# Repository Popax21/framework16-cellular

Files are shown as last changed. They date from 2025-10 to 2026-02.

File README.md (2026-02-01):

# Framework Laptop 16 M.2 Cellular Modem Expansion Bay Module

> [!IMPORTANT]
> ### This design is still a work-in-progress, and should currently be considered non-functional!
>
> The current revision contained in this repository (v1.1) still has some glaring design defects, and as such will need at least one more revision to fully bug-fix.
> As of now I am focusing on other projects, so there is no timeline for when development of the module will resume.

This repository holds the WIP design files for a module for the Framework Laptop 16's Expansion Bay allowing for the connection of a standard M.2 B-Key cellular modem, also featuring a microSIM connector for the insertion of a standard SIM card.
It was designed for usage with Quectel RM50X / RM5X0-series 5G modules, but other 3.7V-tolerant modules are expected to work as well.

> [!WARNING]
> This module provides the M.2 slot with a VCC of 3.7V, and not the standard 3.3V!
> This is the recommended voltage of the Quectel modems the module is designed around, but you may have to adapt the schematic in case you want to use a different module.

The module provides the M.2 slot with both a PCI-E x1 interface as well as an USB2 HS (max 480Mbps) interface, however routing priority has been given to the PCI-E lane, so the full bandwith may not be available over the USB port.
Note that no USB3.x interface has been routed to the slot!
This means that in practice you should be able to use any M.2 cellular module, however only PCI-E capable modules will be able to provide high-speed connectivity.

> [!NOTE]
> This design decision is rooted in the Expanion Bay's interface to the rest of the computer, which only provides a single USB2 port for modules to use.
> Providing a full USB 3.0 (or higher) interface for the modem would have required the addition of a PCI-E USB host controller, which would have in turn complicated the PCI-E logic since now two separate REFCLK signals would be required.
> While there is support for receiving two separate REFCLKs from the mainboard since hardware revision 7, no such support was implemented to reduce the design complexity of the module.

Some functionality exposed by the board (i.e. hardware rfkill/airplane mode, modem resets / power-on shutdowns) are exposed behind an I2C GPIO port, and will require support from the Framework Laptop 16's EC (Embedded Controller) MCU to fully operate.
No such support has been developed as of now, however such support is planned to be released at a future date in the form of firmware patches.

All Expansion Bay modules feature an EEPROM which holds a "descriptor" for the installed module, which contains, among other things, the module's serial number as well as GPIO configuration.
By default the module should be picked as a Dual M.2 Expansion module until an appropriate descriptor has been written onto the EEPROM.
The PCB has been designed to still operate when treated as such an expansion module, however a proper custom EEPROM descriptor will be developed at a future date as part of EC integration.

No pre-packaged schematics / Gerber files are available at the moment, but a GH Actions pipeline may be set up at a future date.

> [!IMPORTANT]
> If you still plan on ordering a PCB through e.g. JLCPCB, ensure that you enable Impedance Matching and specifically select stackup JLC041611H-3313 as part of the checkout process.
> This stackup is required for the sensitive PCI-E / USB / RF signals to be properly impedance matched and not be distorted.

This design uses modified versions of the template PCB and FX Beam connector symbol / footprint published by jyancat, found [here](https://github.com/jyancat/ExpansionBay/tree/main/Electrical/KiCad_templates/Expansion_Bay).

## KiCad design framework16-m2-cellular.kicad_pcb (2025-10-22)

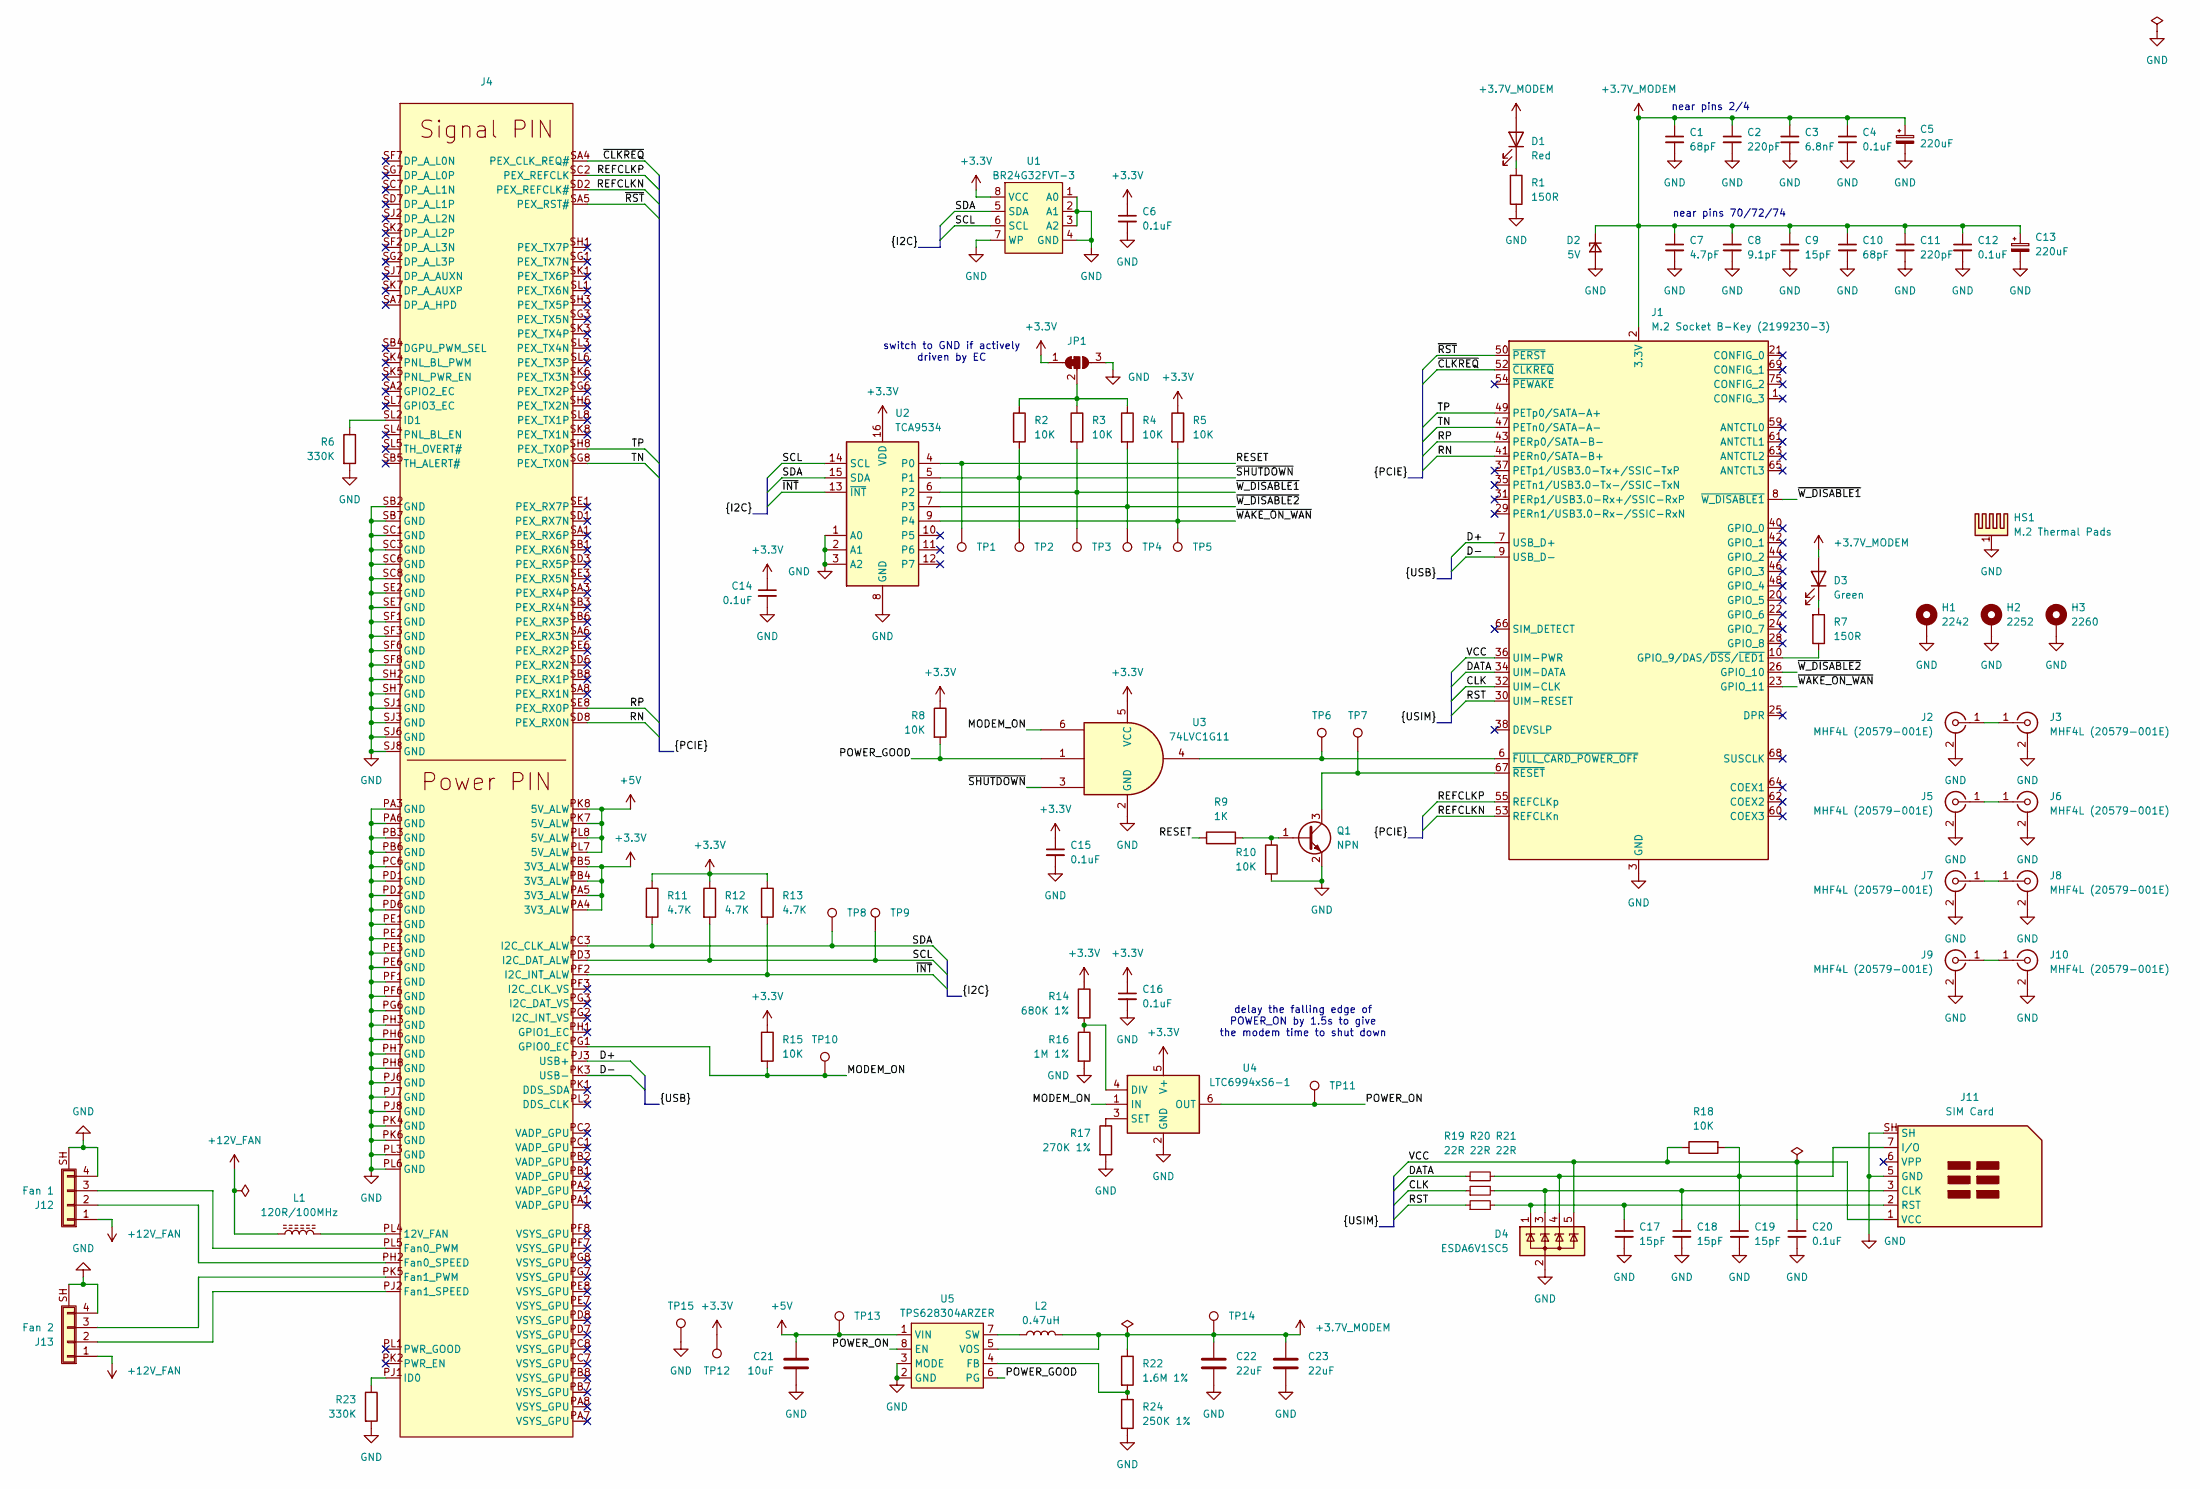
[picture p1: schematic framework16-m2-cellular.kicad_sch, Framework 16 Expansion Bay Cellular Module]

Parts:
C1, C10: 68pF; C_0603_1608Metric; LCSC C62782
C2, C11: 220pF; C_0603_1608Metric; LCSC C106210
C3: 6.8nF; C_0603_1608Metric; LCSC C162241
C4, C6, C12, C14, C15, C16, C20: 0.1uF; C_0603_1608Metric; LCSC C14663
C5, C13: 220uF; CP_Elec_6.3x5.4; LCSC C72494
C7: 4.7pF; C_0603_1608Metric; LCSC C1669
C8: 9.1pF; C_0603_1608Metric; LCSC C61817
C9, C17, C18, C19: 15pF; C_0603_1608Metric; LCSC C1644
C21: 10uF; C_0603_1608Metric; LCSC C19702
C22, C23: 22uF; C_1206_3216Metric; LCSC C90146
D1: Red; LED_0805_2012Metric; LCSC C94741
D2: 5V; D_SOD-523; LCSC C20932
D3: Green; LED_0805_2012Metric; LCSC C2297
D4: ESDA6V1SC5; SOT-23-5; LCSC C2935146
H1: 2242; MountingHole_2.2mm_M2_Pad
H2: 2252; MountingHole_2.2mm_M2_Pad
H3: 2260; MountingHole_2.2mm_M2_Pad
HS1: M.2 Thermal Pads; Thermal Pad
J1: M.2 Socket B-Key (2199230-3); CONN67_2199230_TEC; LCSC C590859
J2, J5, J7, J9: MHF4L (20579-001E); CONN_20579-001E_IPX; LCSC C434808
J3, J6, J8, J10: MHF4L (20579-001E); CONN_20579-001E_IPX; LCSC C5881005
J4: Expansion Bay FXBeam
J11: SIM Card; microSIM_JAE_SF53S006VCBR2000; LCSC C2929301
J12: Fan 1; AFC30-S04FCC-00; LCSC C395232
J13: Fan 2; AFC30-S04FCC-00; LCSC C395232
JP1: SolderJumper_3_Bridged12; SolderJumper-3_P1.3mm_Bridged12_RoundedPad1.0x1.5mm
L1: 120R/100MHz; R_0603_1608Metric; LCSC C14709
L2: 0.47uH; L_1008_2520Metric; LCSC C519277
Q1: NPN; SOT-23; LCSC C916392
R1, R7: 150R; R_0603_1608Metric; LCSC C22808
R2, R3, R4, R5, R8, R10, R15, R18: 10K; R_0603_1608Metric; LCSC C25804
R6, R23: 330K; R_0603_1608Metric; LCSC C23137
R9: 1K; R_0603_1608Metric; LCSC C21190
R11, R12, R13: 4.7K; R_0603_1608Metric; LCSC C23162
R14: 680K 1%; R_0603_1608Metric; LCSC C25822
R16: 1M 1%; R_0603_1608Metric; LCSC C22935
R17: 270K 1%; R_0603_1608Metric; LCSC C22965
R19, R20, R21: 22R; R_0603_1608Metric; LCSC C23345
R22: 1.6M 1%; R_0805_2012Metric; LCSC C5121530
R24: 250K 1%; R_0805_2012Metric; LCSC C5156563
TP1, TP2, TP3, TP4, TP5, TP6, TP7, TP8, TP9, TP10, TP11, TP12, TP13, TP14, TP15: TestPoint; TestPoint_Pad_D1.0mm
U1: BR24G32FVT-3; TSSOP-8_4.4x3mm_P0.65mm; LCSC C2061284
U2: TCA9534; TSSOP-16_4.4x5mm_P0.65mm; LCSC C783615
U3: 74LVC1G11; SOT-23-6; LCSC C22356918
U4: LTC6994xS6-1; TSOT-23-6; LCSC C581054
U5: TPS628304ARZER; WQFN-HR8_RZE_TEX; LCSC C33092582

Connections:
+3.3V: C6.1, C14.1, C15.1, C16.1, J4.PA4 (3V3_ALW), J4.PA5 (3V3_ALW), J4.PB4 (3V3_ALW), J4.PB5 (3V3_ALW), JP1.1 (A), R5.1, R8.1, R11.1, R12.1, R13.1, R14.1, R15.1, TP12.1, U1.8 (VCC), U2.16 (VDD), U3.5 (VCC), U4.5 (V+)
+3.7V_MODEM: C1.1, C2.1, C3.1, C4.1, C5.1, C7.1, C8.1, C9.1, C10.1, C11.1, C12.1, C13.1, C22.1, C23.1, D1.2 (A), D2.1 (K), D3.2 (A), J1.2 (3.3V), J1.4 (3.3V), J1.70 (3.3V), J1.72 (3.3V), J1.74 (3.3V), L2.2, R22.1, TP14.1, U5.5 (VOS)
+5V: C21.1, J4.PK7 (5V_ALW), J4.PK8 (5V_ALW), J4.PL7 (5V_ALW), J4.PL8 (5V_ALW), TP13.1, U5.1 (VIN)
+12V_FAN: J12.1, J13.1, L1.1
/CLK: J1.32 (UIM-CLK), R20.1
/D+: J1.7 (USB_D+), J4.PJ3 (USB+)
/D-: J1.9 (USB_D-), J4.PK3 (USB-)
/DATA: J1.34 (UIM-DATA), R19.1
/MODEM_ON: J4.PG1 (GPIO0_EC), R15.2, TP10.1, U3.6, U4.1 (IN)
/POWER_GOOD: R8.2, U3.1, U5.6 (PG)
/POWER_ON: TP11.1, U4.6 (OUT), U5.8 (EN)
/REFCLKN: J1.53 (REFCLKn), J4.SD2 (PEX_REFCLK#)
/REFCLKP: J1.55 (REFCLKp), J4.SC2 (PEX_REFCLK)
/RESET: R9.1, TP1.1, U2.4 (P0)
/RN: J1.41 (PERn0/SATA-B+), J4.SD8 (PEX_RX0N)
/RP: J1.43 (PERp0/SATA-B-), J4.SE8 (PEX_RX0P)
/RST: J1.30 (UIM-RESET), R21.1
/SCL: J4.PD3 (I2C_DAT_ALW), R12.2, TP9.1, U1.6 (SCL), U2.14 (SCL)
/SDA: J4.PC3 (I2C_CLK_ALW), R11.2, TP8.1, U1.5 (SDA), U2.15 (SDA)
/TN: J1.47 (PETn0/SATA-A-), J4.SG8 (PEX_TX0N)
/TP: J1.49 (PETp0/SATA-A+), J4.SH8 (PEX_TX0P)
/VCC: C20.1, D4.5 (K), J1.36 (UIM-PWR), J11.1 (VCC), R18.1
/~CLKREQ: J1.52 (~CLKREQ), J4.SA4 (PEX_CLK_REQ#)
/~INT: J4.PF2 (I2C_INT_ALW), R13.2, U2.13 (~INT)
/~RST: J1.50 (~PERST), J4.SA5 (PEX_RST#)
/~SHUTDOWN: R2.2, TP2.1, U2.5 (P1), U3.3
/~WAKE_ON_WAN: J1.23 (GPIO_11), R5.2, TP5.1, U2.9 (P4)
/~W_DISABLE1: J1.8 (~W_DISABLE1), R3.2, TP3.1, U2.6 (P2)
/~W_DISABLE2: J1.26 (GPIO_10), R4.2, TP4.1, U2.7 (P3)
GND: C1.2, C2.2, C3.2, C4.2, C5.2, C6.2, C7.2, C8.2, C9.2, C10.2, C11.2, C12.2, C13.2, C14.2, C15.2, C16.2, C17.2, C18.2, C19.2, C20.2, C21.2, C22.2, C23.2, D2.2 (A), D4.2 (A), H1.1, H2.1, H3.1, HS1.1, J1.3 (GND), J1.5 (GND), J1.11 (GND), J1.27 (GND), J1.33 (GND), J1.39 (GND), J1.45 (GND), J1.51 (GND), J1.57 (GND), J1.71 (GND), J1.73 (GND), J2.2 (Ext), J3.2 (Ext), J4.PA3 (GND), J4.PA6 (GND), J4.PB3 (GND), J4.PB6 (GND), J4.PC6 (GND), J4.PD1 (GND), J4.PD2 (GND), J4.PD6 (GND), J4.PE1 (GND), J4.PE2 (GND), J4.PE3 (GND), J4.PE6 (GND), J4.PF1 (GND), J4.PF6 (GND), J4.PG6 (GND), J4.PH3 (GND), J4.PH6 (GND), J4.PH7 (GND), J4.PH8 (GND), J4.PJ6 (GND), J4.PJ7 (GND), J4.PJ8 (GND), J4.PK4 (GND), J4.PK6 (GND), J4.PL3 (GND), J4.PL6 (GND), J4.SB2 (GND), J4.SB7 (GND), J4.SC1 (GND), J4.SC3 (GND), J4.SC6 (GND), J4.SC8 (GND), J4.SE2 (GND), J4.SE7 (GND), J4.SF1 (GND), J4.SF3 (GND), J4.SF6 (GND), J4.SF8 (GND), J4.SH2 (GND), J4.SH7 (GND), J4.SJ1 (GND), J4.SJ3 (GND), J4.SJ6 (GND), J4.SJ8 (GND), J5.2 (Ext), J6.2 (Ext), J7.2 (Ext), J8.2 (Ext), J9.2 (Ext), J10.2 (Ext), J11.5 (GND), J11.SH, J12.4, J12.SH (Shield), J13.4, J13.SH (Shield), JP1.3 (B), Q1.2 (E), R1.1, R6.2, R10.2, R16.2, R17.2, R23.2, R24.2, TP15.1, U1.1 (A0), U1.2 (A1), U1.3 (A2), U1.4 (GND), U1.7 (WP), U2.1 (A0), U2.2 (A1), U2.3 (A2), U2.8 (GND), U3.2 (GND), U4.2 (GND), U5.2 (GND), U5.3 (MODE); also elsewhere on the board
unnamed: D1.1 (K), R1.2
unnamed: D3.1 (K), R7.2
unnamed: J1.10 (GPIO_9/DAS/~DSS/~LED1), R7.1
unnamed: J1.6 (~FULL_CARD_POWER_OFF), TP6.1, U3.4
unnamed: J1.67 (~RESET), Q1.3 (C), TP7.1
unnamed: J2.1 (In), J3.1 (In)
unnamed: J4.PL4 (12V_FAN), L1.2
unnamed: J4.PJ1 (ID0), R23.1
unnamed: J4.SL2 (ID1), R6.1
unnamed: J5.1 (In), J6.1 (In)
unnamed: J7.1 (In), J8.1 (In)
unnamed: J9.1 (In), J10.1 (In)
unnamed: C18.1, D4.3 (K), J11.3 (CLK), R20.2
unnamed: C19.1, D4.4 (K), J11.7 (I/O), R18.2, R19.2
unnamed: C17.1, D4.1 (K), J11.2 (RST), R21.2
unnamed: J4.PH2 (Fan0_SPEED), J12.2
unnamed: J4.PL5 (Fan0_PWM), J12.3
unnamed: J4.PJ2 (Fan1_SPEED), J13.2
unnamed: J4.PK5 (Fan1_PWM), J13.3
unnamed: JP1.2 (C), R2.1, R3.1, R4.1
unnamed: Q1.1 (B), R9.2, R10.1
unnamed: R14.2, R16.1, U4.4 (DIV)
unnamed: R17.1, U4.3 (SET)
unnamed: R22.2, R24.1, U5.4 (FB)
unnamed: L2.1, U5.7 (SW)

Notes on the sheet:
delay the falling edge of POWER_ON by 1.5s to give the modem time to shut down
near pins 70/72/74
near pins 2/4
switch to GND if actively driven by EC

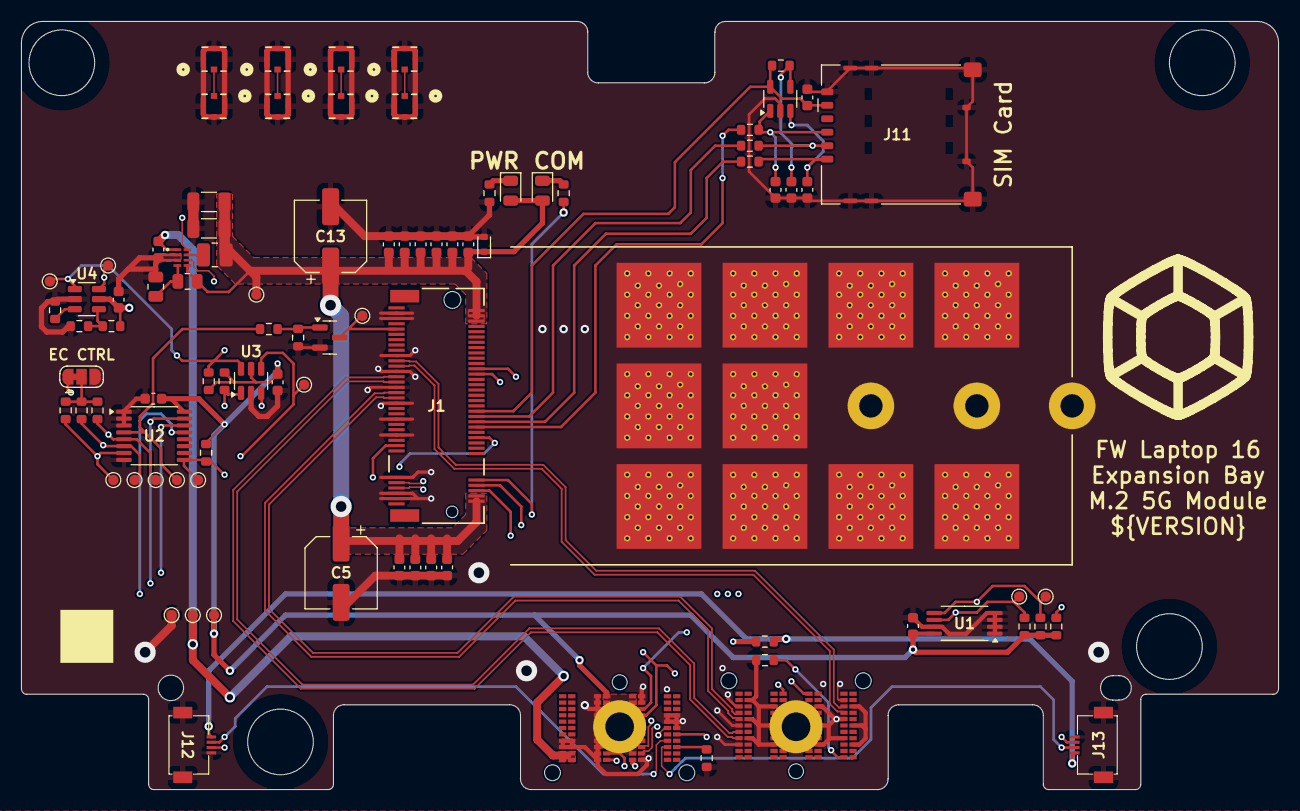
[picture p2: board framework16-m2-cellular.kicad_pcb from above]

Board: 4 copper layers, 118.7 x 72.5 mm, 101 parts (0 on the bottom side), 55 nets.

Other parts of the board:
HS1#2, HS1#3, HS1#4, HS1#5, HS1#6, HS1#7, HS1#8, HS1#9, HS1#10: M.2 Thermal Pads; Thermal Pad

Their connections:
GND: HS1#2.1, HS1#3.1, HS1#4.1, HS1#5.1, HS1#6.1, HS1#7.1, HS1#8.1, HS1#9.1, HS1#10.1; also elsewhere on the board

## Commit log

2025-06-01 Version v1.0
    [framework16-m2-cellular.kicad_pcb, framework16-m2-cellular.kicad_sch]
2025-06-01 Version v1.1
    [framework16-m2-cellular.kicad_pcb, framework16-m2-cellular.kicad_sch]
2025-06-04 Bunch of improvements for v1.1
    [framework16-m2-cellular.kicad_pcb, framework16-m2-cellular.kicad_sch]
2025-06-11 Fixes from v1.1
    TODO: check the orientation of the fan headers
    [framework16-m2-cellular.kicad_pcb, framework16-m2-cellular.kicad_sch]
2025-09-01 Remove EEPROM address jumper
    [framework16-m2-cellular.kicad_pcb, framework16-m2-cellular.kicad_sch]
2025-09-01 Fix flipped fan connector
    [framework16-m2-cellular.kicad_pcb, framework16-m2-cellular.kicad_sch]
2025-09-01 Fix incorrect fan header description
    [framework16-m2-cellular.kicad_sch]
2025-09-01 Random KiCAD changes
    [framework16-m2-cellular.kicad_pcb]
2025-10-22 Add solder pads for screw standoffs
    [framework16-m2-cellular.kicad_pcb]
2025-11-03 Swap out capacitors with more low profile ones
    [framework16-m2-cellular.kicad_sch]
2026-02-01 Add current project status disclaimer
